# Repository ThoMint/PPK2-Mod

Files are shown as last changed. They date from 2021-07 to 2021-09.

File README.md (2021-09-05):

# PPK2-Mod

This Repository contains the documentaion for a PPK2 Modification.
The Mod extends the measurement range of the power profiler (x10 higher current resolution in the lowes range).
Further information can be found here: [Mod-Doku](https://github.com/ThoMint/PPK2-Mod/blob/master/PPK2-Mod-Bericht.pdf)

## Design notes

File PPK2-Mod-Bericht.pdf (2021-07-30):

## PPK2 Mod

Ziel des Projekts ist die Bereichserweiterung eines PPK2s, dem Power Profiling Kit von Nordic. PC Software und Hardware ist Open Source. Die Messbereichserweiterung soll die Auflösung im Nano-Ampere-Bereich erhöhen.

Das PPK2 erreicht seine hohe Dynamik über 5 Ranges die analog durchgeschalten werden.
Der Range Switch wird durch Über- oder Unterspannung am Ausgang des Instrumentation Amplifiers ausgelöst.

Da der Range Switch somit unabhängig von den jeweiligen Shunt-Widerständen schaltet ist eine Messbereichsverschiebung leicht möglich indem alle Shunt-Widerstände um eine Dekade erhöht werden.

Simulationen

…zur weiteren Evaluierung und zum Verständnis der weniger gut dokumentierten Schaltung

Simulationsprogramm: Microcap

Instrumentation Amplifier

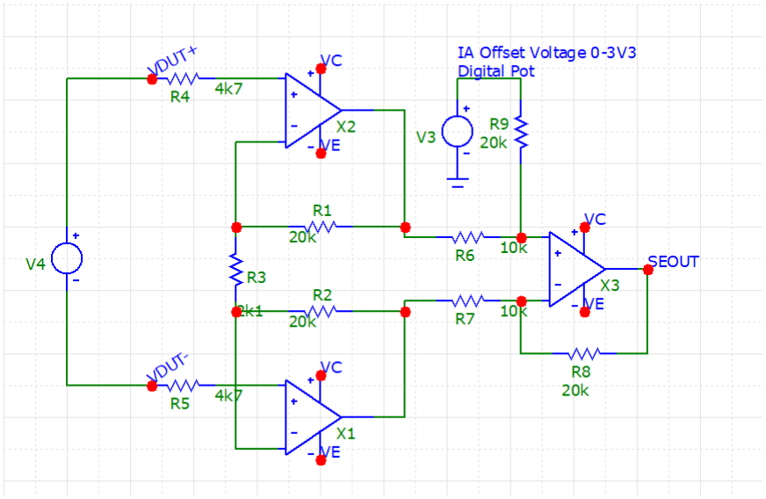
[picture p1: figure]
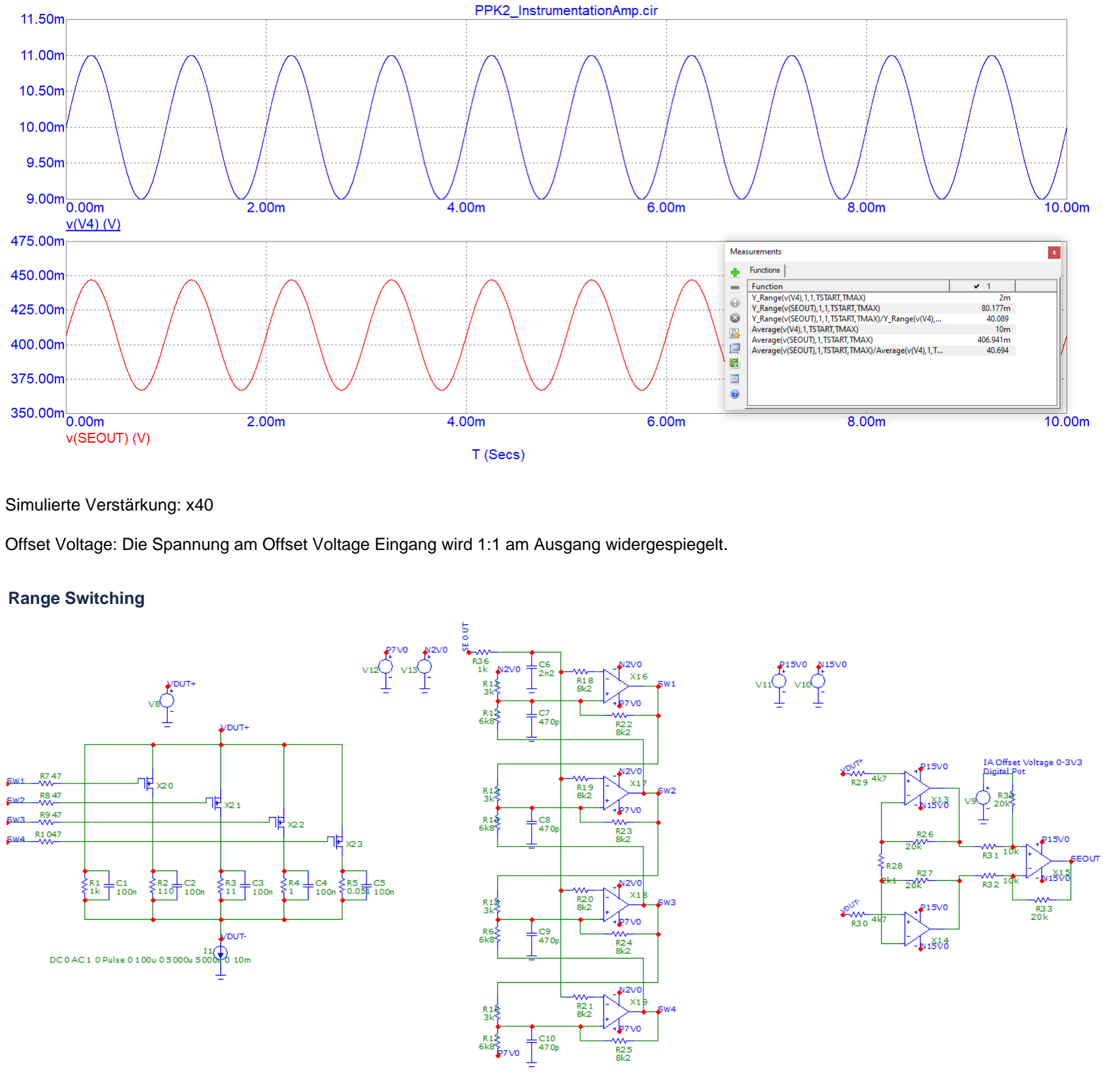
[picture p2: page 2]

Simulierte Verstärkung: x40

Offset Voltage: Die Spannung am Offset Voltage Eingang wird 1:1 am Ausgang widergespiegelt.

Range Switching

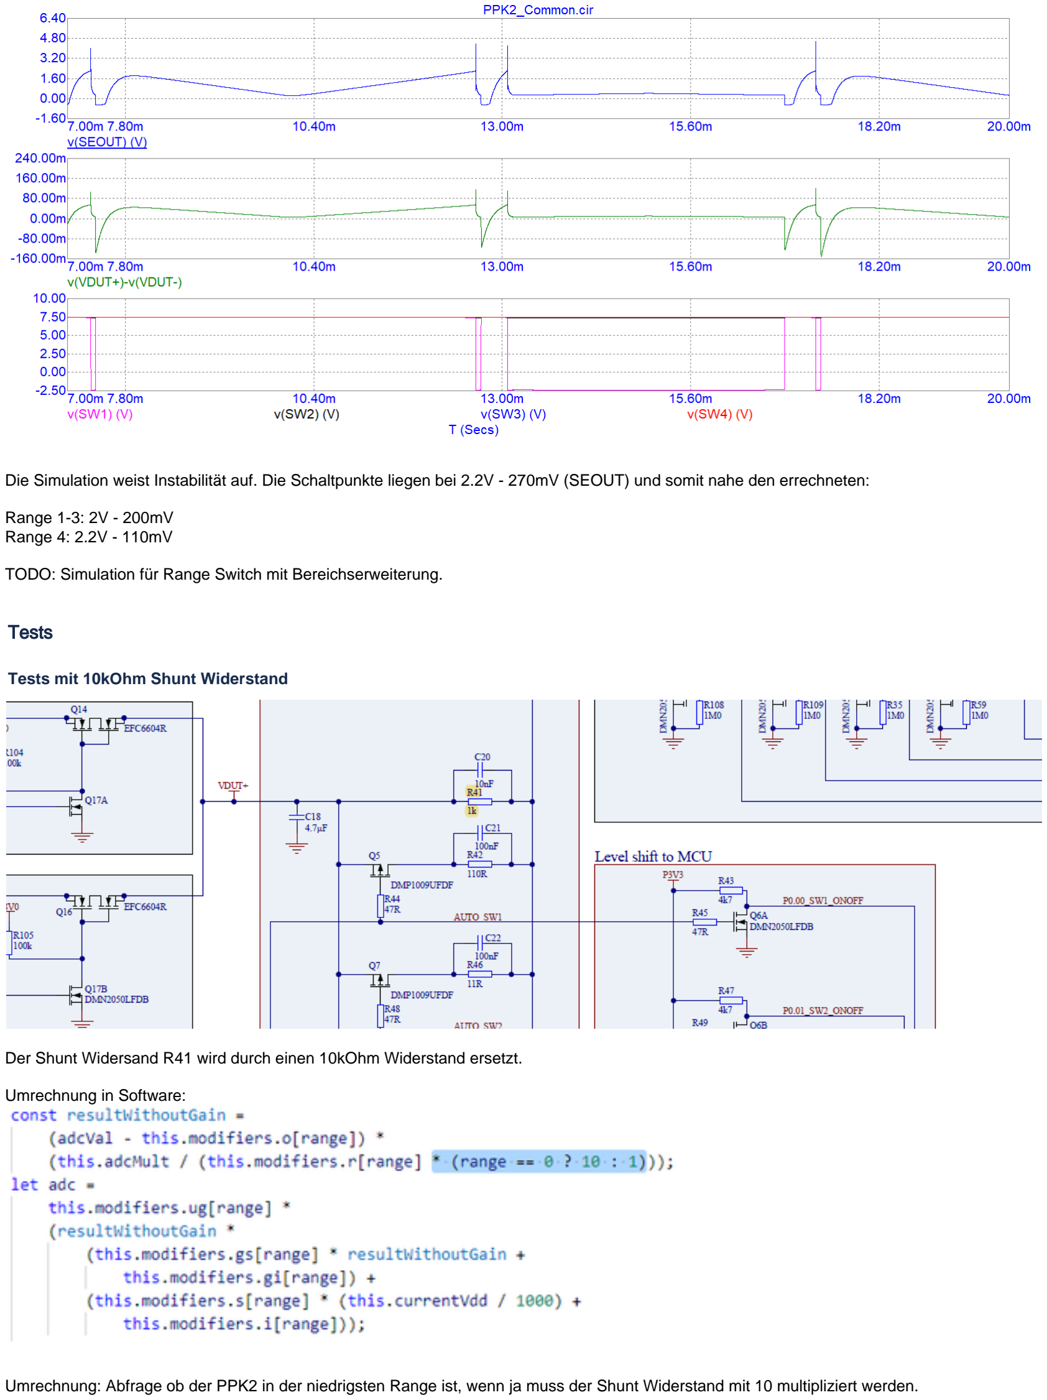
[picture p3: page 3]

Die Simulation weist Instabilität auf. Die Schaltpunkte liegen bei 2.2V - 270mV (SEOUT) und somit nahe den errechneten:

Range 1-3: 2V - 200mV
Range 4: 2.2V - 110mV

TODO: Simulation für Range Switch mit Bereichserweiterung.

Tests

Tests mit 10kOhm Shunt Widerstand

Der Shunt Widersand R41 wird durch einen 10kOhm Widerstand ersetzt.

Umrechnung in Software:

Umrechnung: Abfrage ob der PPK2 in der niedrigsten Range ist, wenn ja muss der Shunt Widerstand mit 10 multipliziert werden.

Resultat: Durch fehlende Kalibration und 1% Widerstandstoleranz ist das Ergebnis im richtigen Bereich aber nicht exakt.

Bei ungünstigen Lastströmen begibt sich der analoge Range Switch in eine Oszillation da die vorhandene Hysterese nicht mehr ausreicht um den Messbereich über 2 Dekaden hinweg stabil zu halten.

Tests mit Messbereichsversatz

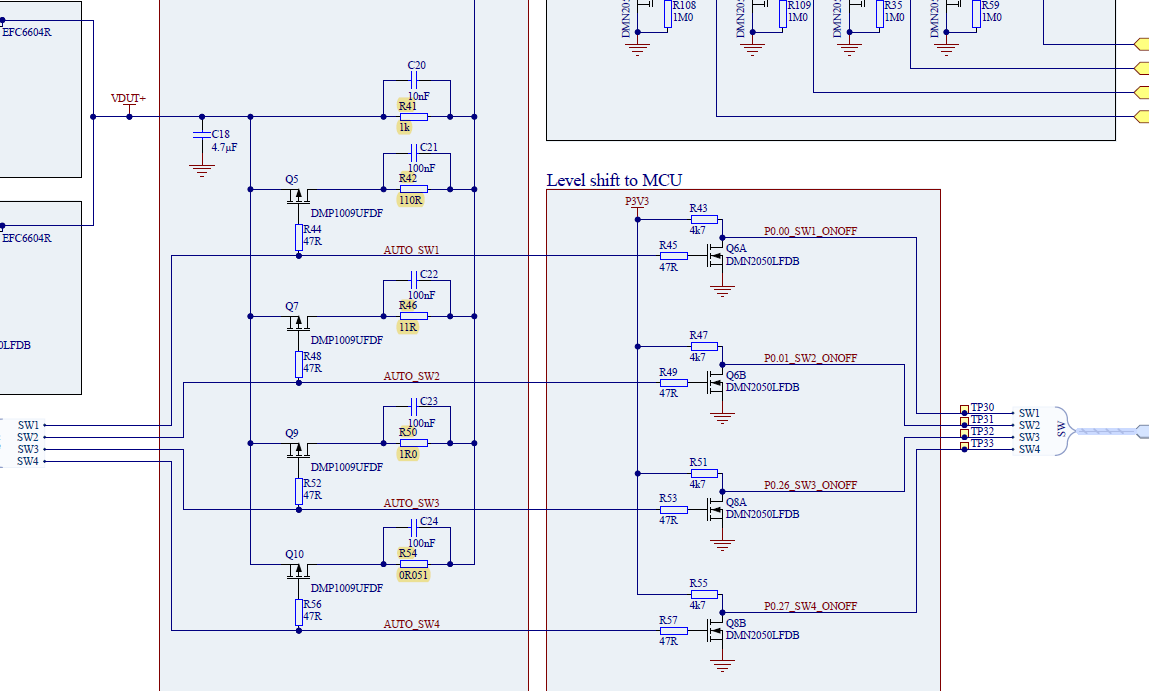
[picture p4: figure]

R41,R42,R46,R50,R54 werden jeweils um eine Dekade (Faktor x10) erhöht. Dadurch verschiebt sich der Messbereich. Das PPK2 verliert dadurch seine High Current Capabilities, gewinnt jedoch Auflösung im nA Bereich.

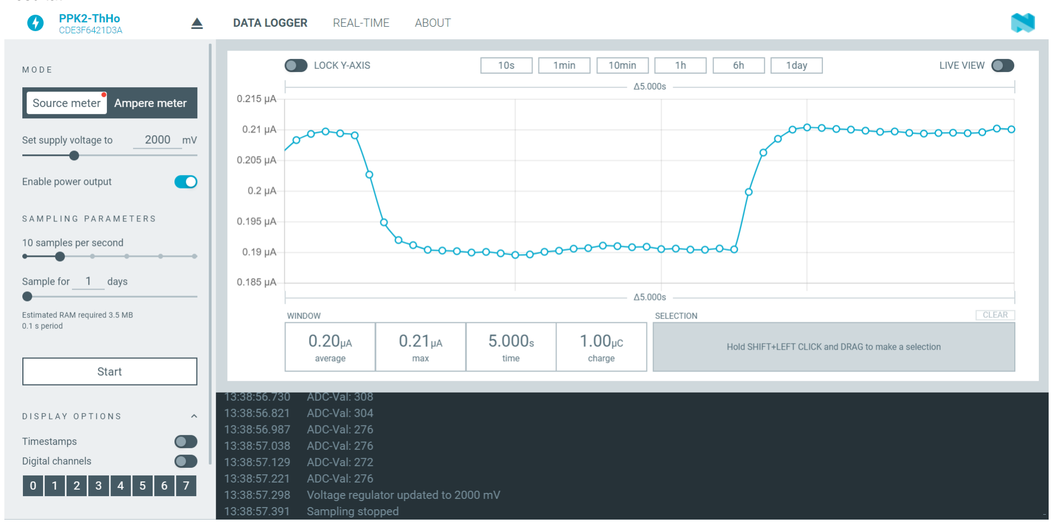
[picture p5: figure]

Resultat:

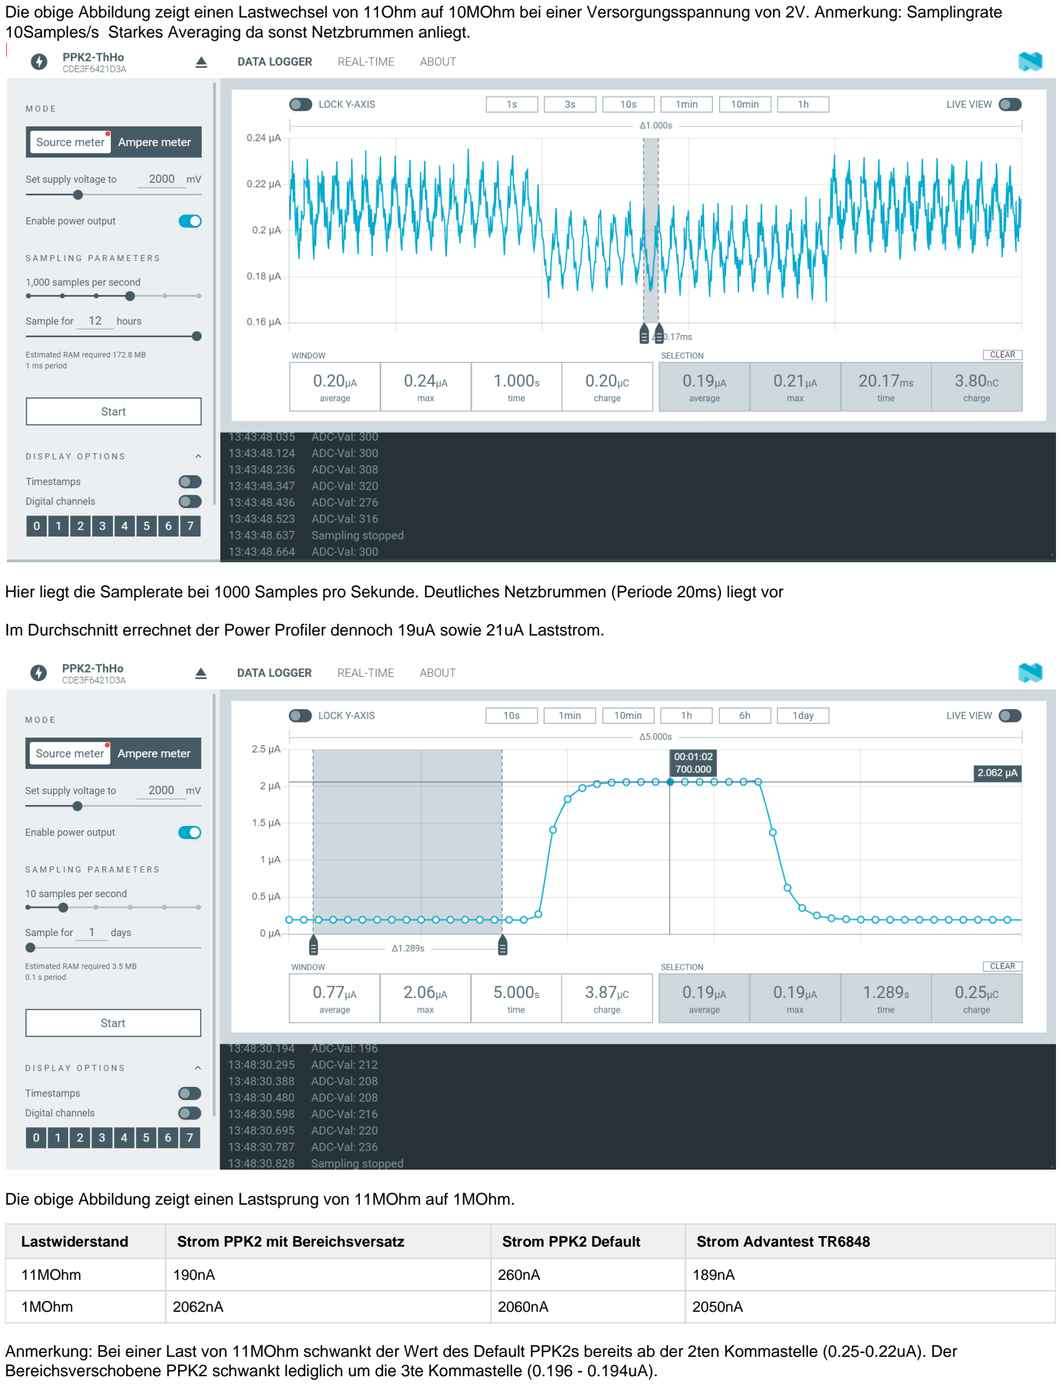
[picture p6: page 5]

Die obige Abbildung zeigt einen Lastwechsel von 11Ohm auf 10MOhm bei einer Versorgungsspannung von 2V. Anmerkung: Samplingrate 10Samples/s Starkes Averaging da sonst Netzbrummen anliegt.

Hier liegt die Samplerate bei 1000 Samples pro Sekunde. Deutliches Netzbrummen (Periode 20ms) liegt vor

Im Durchschnitt errechnet der Power Profiler dennoch 19uA sowie 21uA Laststrom.

Die obige Abbildung zeigt einen Lastsprung von 11MOhm auf 1MOhm.

Lastwiderstand | Strom PPK2 mit Bereichsversatz | Strom PPK2 Default | Strom Advantest TR6848
11MOhm | 190nA | 260nA | 189nA
1MOhm | 2062nA | 2060nA | 2050nA

Anmerkung: Bei einer Last von 11MOhm schwankt der Wert des Default PPK2s bereits ab der 2ten Kommastelle (0.25-0.22uA). Der Bereichsverschobene PPK2 schwankt lediglich um die 3te Kommastelle (0.196 - 0.194uA).

Da durch die vorherigen Tests eine Bereichserweiterung sinnvoll erscheint wird diese in den nächsten Schritten durchgeführt und getestet.

Bereichserweiterung 1A-10nA

Hardwareänderungen

Da die Messbereiche vorwiegend von den Shunt-Widerständen abhängen können diese einfach ausgetauscht werden indem man alle Widerstandswerte x10 multipliziert. Dadurch wird der Messbereich verschoben. Da das gewünschte Ergebnis jedoch eine Messbereichserweiterung ist muss hier der kleinste Shunt Widerstand gleich bleiben. Der kleinste Messbereich wird um einen Faktor 10 verkleinert.

Die Bereiche dazwischen müssen nun anders aufgeteilt werden. Eine logarithmische Verteilung ist notwendig:

Dimensionierung der Bereich mit Python per Geomspace (NumPy):
https://trinket.io/python3/8aac81c5b8

Daraus ergeben sich folgende Logarithmisch verteilten Widerstandswerte: 50mOhm, 1Ohm, 22Ohm, 470Ohm, 10kOhm

Herstellernummern:

ERJL03KF50MV

ERA3APB471V

RT0603DRD0710KL

CRCW06031R00FKEAHP

ERJ3RED22R0V

Widerstandsgehäuse: 0603, Original-Footprint: 0402

Größere Widerstandsgehäuse haben von Natur aus weniger Eigenerwärmung und sind somit besser als Shunt-Widerstände geeignet. Problematik: Mögliche kalte Lötstellen da die Pads nicht gut erreichbar sind.

Problematik: Durch die höheren Messbereiche ergeben sich auch andere Spannungspegel am Ausgang des Instrumentation Amplifiers. Der Automatic Range Switch schaltet dadurch nicht mehr richtig und begibt sich bei einigen Stromwerten zwischen den Bereichen in eine Oszillation. (Starkes Negatives Feedback wie bereits in der Simulation zu sehen)

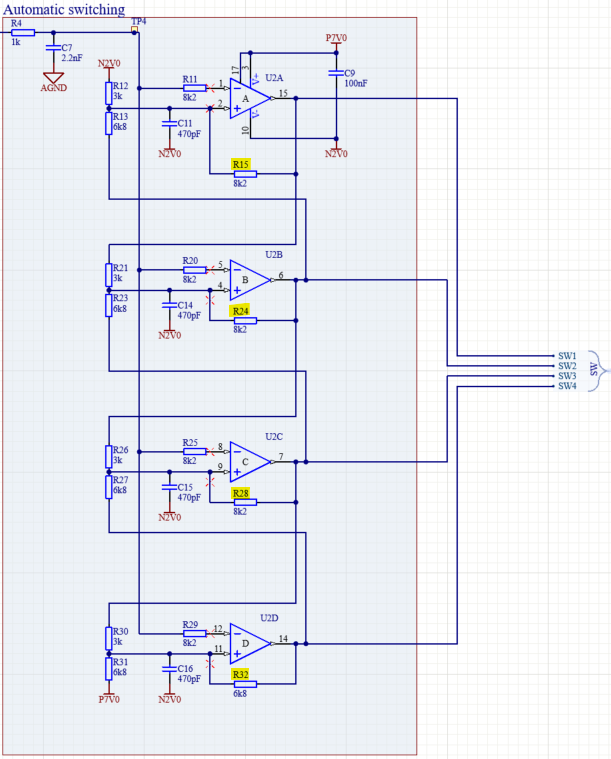
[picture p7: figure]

Die Widerstände R15, R24, R28, R32 bestimmen die Hysterese und somit auch die Schaltschwellen. Kleiner Widerstandswerte an diesen Stellen ergeben eine höhere Hysterese und somit einen weiteren Bereich bis zur nächsten Schaltschwelle (Hysterese durch verschieben der Referenzspannung an Vin+).

Dimensionierung: Trial and Error. Durch langsames herantasten (inkrementelles verkleinern der Widerstandswerte) wurden die Widerstände R15, R24, R28, R32 auf 6k2 festgelegt.

Eine weitere Verkleinerung dieser Widerstände bewirkt dass Ranges nicht mehr bzw. zu Spät schalten und somit der ADC oben oder unten an seine Eingangsspannungsgrenzen kommt.

Durch die neuen Range-Hysterese Widerstände ergeben sich ADC-Counts von 150Cnts bis 6000Cnts (ADC Counts nach Gain-Correction, Spannungswerte nahe Aussteuergrenzen, 14Bit ADC)

Softwareänderungen

Die meiste Funktionalität des Geräts wird durch die Software erreicht. Die Firmware liefert lediglich raw ADC Counts sowie die derzeitige Range und beim Verbinden des Geräts die ab-Werk Kalibrationsdaten.

Da die Kalibrationsdaten (auf einem I2C EEPROM auf dem Gerät gespeichert) nicht mit den neuen Widerständen und Bereichen kompatibel sind, muss die Kalibration neu durchgeführt werden.

Das originale Kalibrationsmodell ist unübersichtlich und nicht definierbar. Es bleibt unklar welche Korrekturen hier vorgenommen werden und wie die Faktoren berechnet werden.

Abhilfe: Neues, transparentes Kalibrationsmodell:
9 Punkt (pro Range) Kalibration über Eingangsspannung und Strom.

Kalibrationsdaten der Range 0:

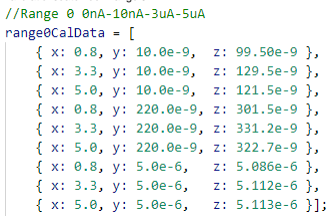
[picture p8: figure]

x: DUT Spannung in V
y: Referenz Strom von bekannter und geeichter Stromquelle
z: Ausgangs Strom des PPK2s ohne Kalibration (Offset = 0 wenn y=z)

Diese Kalibrationsdaten werden bilinear Interpoliert um eine bessere Abdeckung der Range zu erreichen.

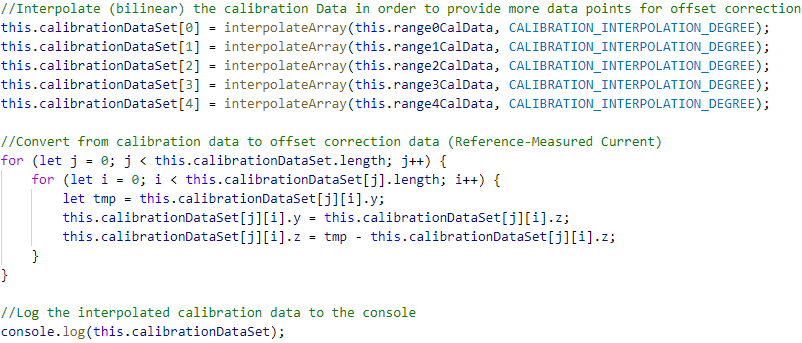
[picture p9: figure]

Interpolation:

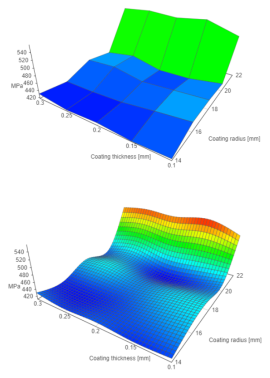
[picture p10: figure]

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
Achtung: Abbildungen nur Symbolbilder, repräsentieren nicht die tatsächlichen Kalibrationsdaten

Durch diese Art der Kalibration ergibt sich ein Abbild des Gesamten Messbereichs.

Umrechnen von ADC Counts zu Strom:

Der Offset wird als der nächste Wert in der Kennlinie (kleinster Abstand über Pythagoras) angenommen.

Weitere Änderungen der Software:

-Debug Statements im Logger der Software (Betriebsspannung, Range, Widerstand, Offset, etc.) -Erhöhung der Kommastellen der Stats Anzeigen (Average, Maximum und Charge)

Kalibrationsvorgang

Kalibrationsdatentabell in “src\device\serialDevice.js” für die entsprechende Range editieren: Gewünschte DUT Spannungen eintragen
Gewünschte Referenz-Ströme eintragen
Ausgangsströme gleich den Referenz-Strömen setzten (y=z->Offset = y-z = 0)
Die Sotware neu Kompillieren. Kompletter Guide zum aufsetzen und kompillieren eines Node.js Projekts unter: https://nordicsemiconductor.github.io/pc-nrfconnect-docs/app_development (https://nordicsemiconductor.github.io/pc-nrfconnect-docs/app_development)
Messtabelle durchgehen
DUT Spannung einstellen
Strom bei Stromquelle einstellen (als Stromsenke!!!)
Warten bis sich das Average-Reading eingestellt hat
Average Current aus der Software nRF Connect in die Tabelle übertragen Code abspeichern und nRF Connect Power Profiler neu kompillieren

Die Referenz - Daten wurden:

-für die DUT Spannung Linear aufgeteilt (0.8V = Min, 3.3V, 5V = Max)

-für den Eingangsstrom geometrisch gemittelt (Range-Min, geom. Mittel der Range, Range-Max)

Der Interpolationsgrad wird über die Konstante CALIBRATION_INTERPOLATION_DEGREE eingestellt.

Weiters müssen die richtigen Widerstandwerte eingetragen werden (“src\device\serialDevice.js:150”) Hier reichen die idealen Werte, der Rest wird durch die Kalibration korrigiert.

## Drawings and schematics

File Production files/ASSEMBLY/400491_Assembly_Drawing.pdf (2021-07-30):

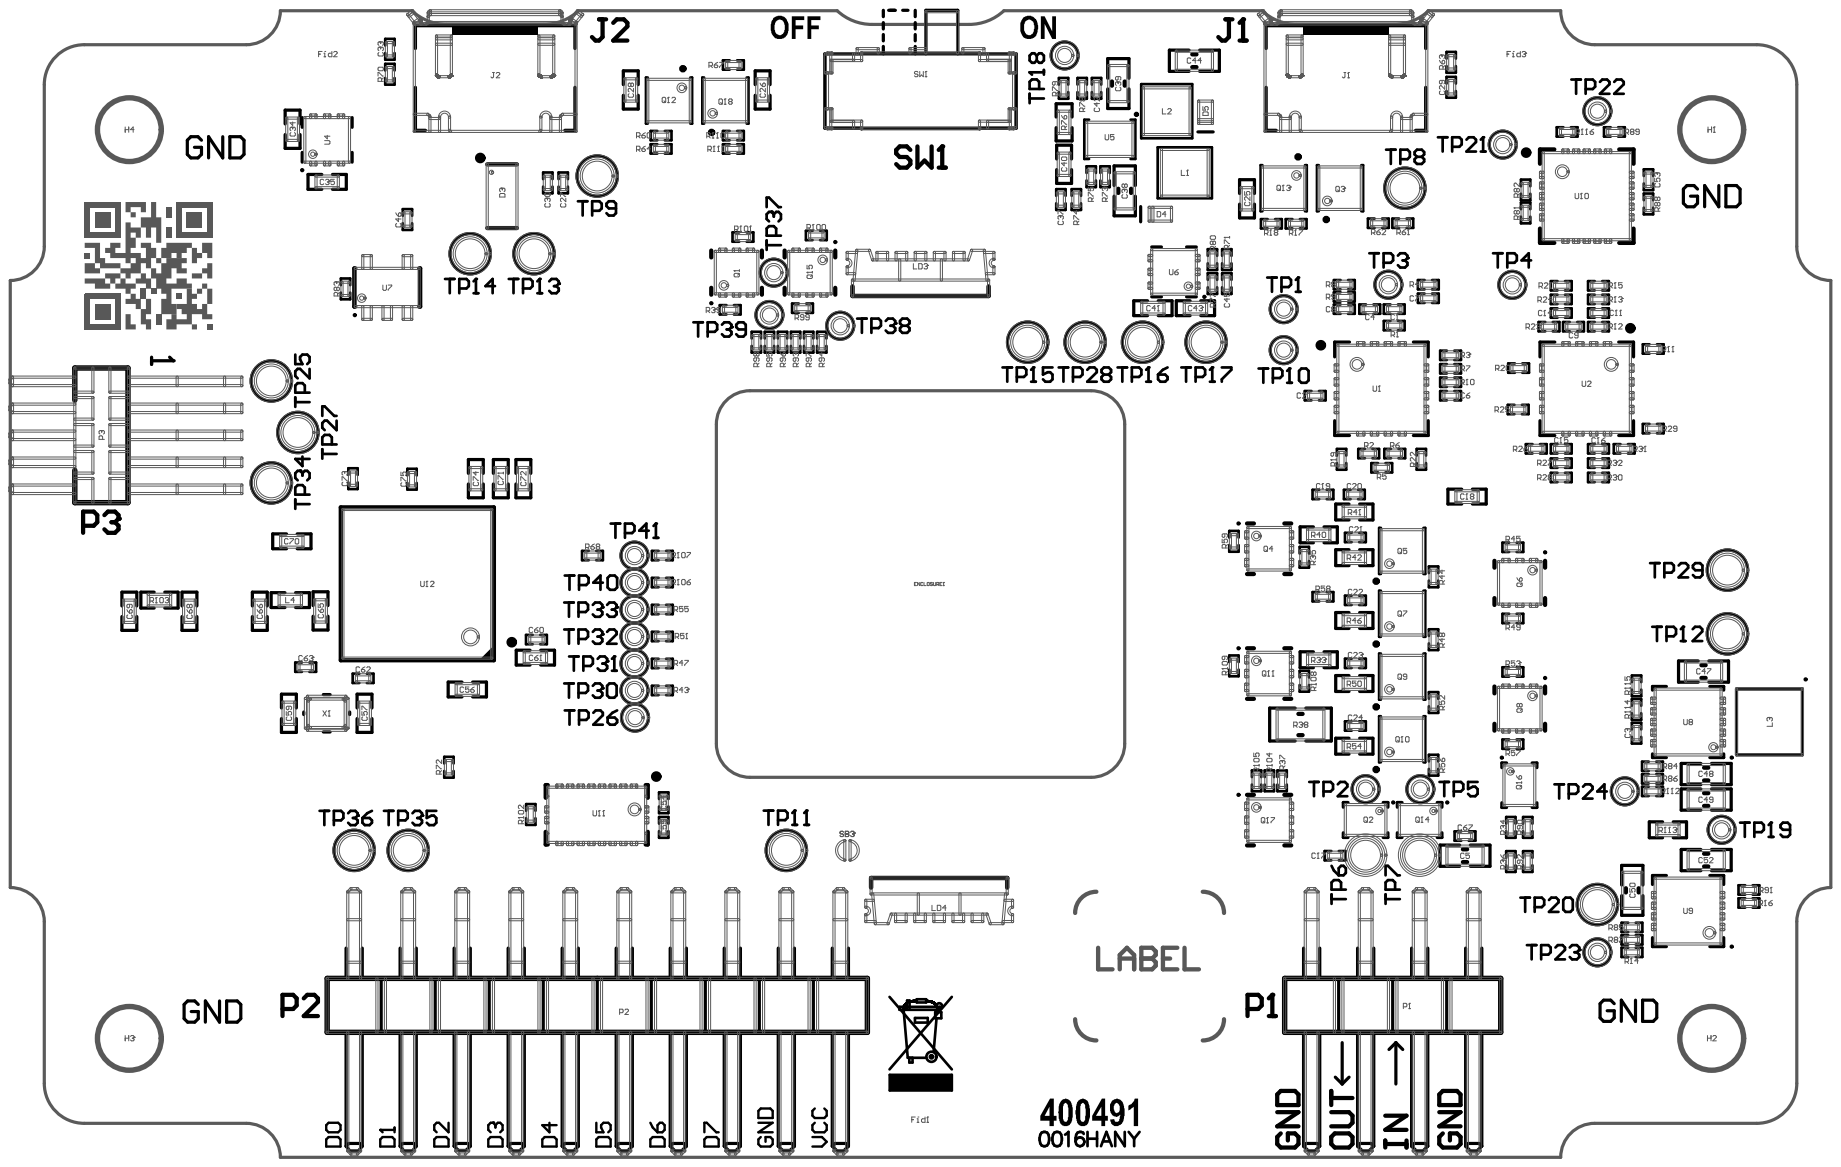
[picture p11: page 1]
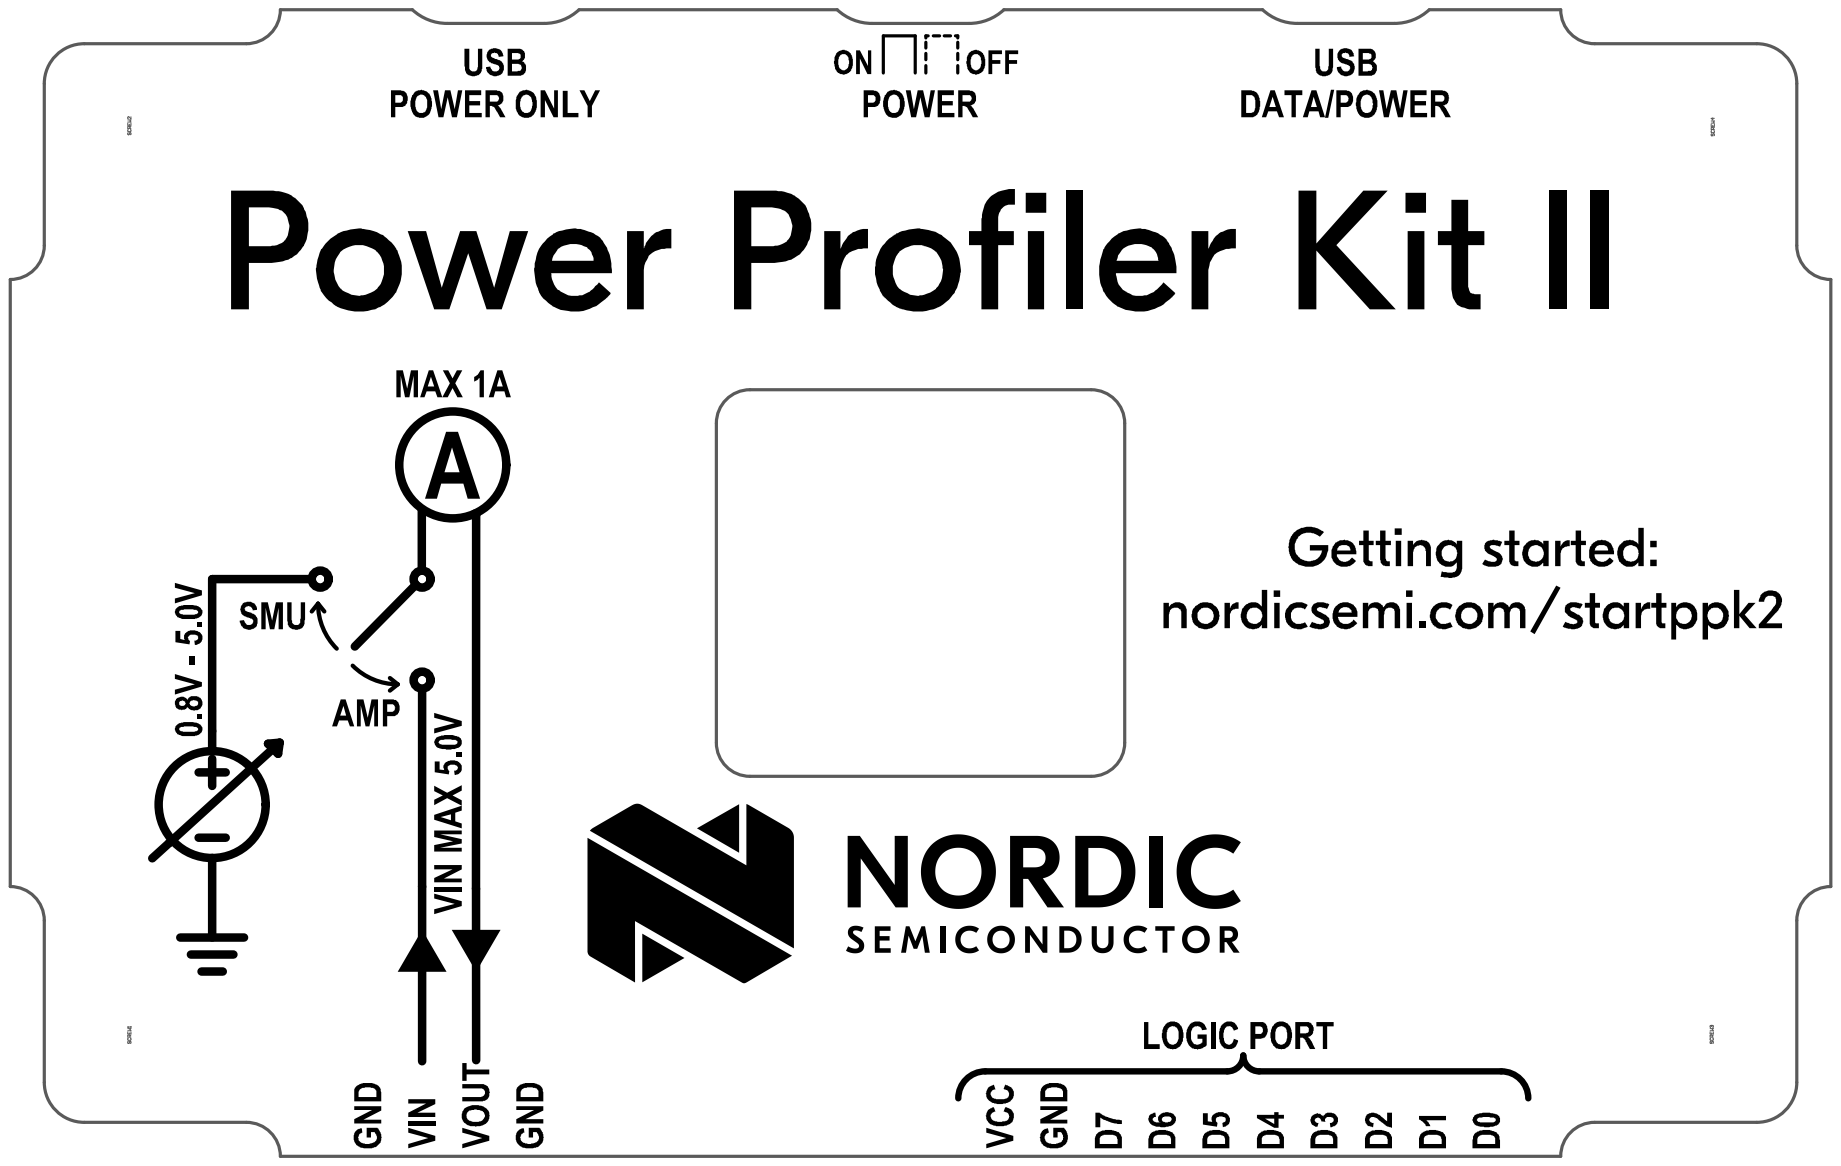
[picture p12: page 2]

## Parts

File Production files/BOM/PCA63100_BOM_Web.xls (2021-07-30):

Bill of material
Board: | pca63100
Version: | 1.0.1
Designator | Value | Description | Fitted | Footprint Doc | Manufacturer | Manufacturer Part Number
C2, C3, C9, C21, C22, C23, C24, C27, C46, C53, C54, C55, C60, C62, C67, C73, C75 | 100nF | Capacitor, X5R, ±10% | Fitted | 0201
C5, C38, C39, C44, C47, C48, C49, C50, C52 | 10µF | CAP CER 10UF 10V X7T 0603 | Fitted | 0603 | Murata | GRM188D71A106MA73
C7, C37, C42 | 2.2nF | Capacitor, X7R, ±10%, 10V | Fitted | 0201
C8 | 1.0nF | Capacitor, X7R, ±10% | Fitted | 0201
C11, C14, C15, C16 | 470pF | Chip Cap 0201 | Fitted | 0201
C17, C19, C20, C30 | 10nF | Capacitor, X7R, ±10% | Fitted | 0201
C18, C25, C26, C28, C34, C35, C41, C43, C71, C72, C74 | 4.7µF | Capacitor, X5R, ±20% | Fitted | 0402
C40, C56, C61 | 1.0µF | Capacitor, X5R, ±5%, 6.3V | Fitted | 0402
C45 | 1.0µF | Capacitor, X5R, ±10% | Fitted | 0201
C57, C59 | 12pF | Capacitor, NP0, ±2% | Fitted | 0402
C63 | 100pF | Capacitor, NP0, ±2%, 25V | Fitted | 0201 | Murata | GRM0335C1E101GA01
C70 | 820pF | Capacitor, NP0, ±5% | Fitted | 0402
D3 | PRTR5V0U2X | Ultra low capacitance double rail-to-rail ESD protection diode | Fitted | SOT-143B | NXP | PRTR5V0U2X
D4, D5 | PMEG2005AELD | DIODE SCHOTTKY 20V 0.5A DFN1006D-2/SOD882D | Fitted | DFN1006D-2 | NXP | PMEG2005AELD, 315
ENCLOSURE1 | Plastic Enclosure | PPK2 Moulded plastic casing | Fitted | Plastic casing | Proto Labs, Inc. | PPK plexi rev 1.2
J1, J2 | MicroUSB-B | MicroUSB-B-SMT | Fitted | USB-Micro-B-RA-SMD-PiP | Allen Creations Corp. | AJU55-BS2111-L
L1, L2 | 4.7µH | Shielded Power Inductor EPL2014 Low DCR Ind 4.7 uH 20 % 650mA | Fitted | IND_EPL2014 | Coilcraft | EPL2014-472MLC
L3 | 1.5µH | Ferrite Inductor, Shielded, 1,8A, 48mOhm | Fitted | 1212 | Taiyo Yuden | NR3015T1R5N
LD3, LD4 | LED RGB | High brightness, side view RGB LED | Fitted | 6922 | ROHM | MSL0104RGBU1
P1 | Pin List 1x4, Angled | Pin List 1x4, 2.54mm (100mil), Right Angled, SMD | Fitted | LIST_ANG_1x4-SMD-2.54MM
P2 | Pin List 1x10, Angled | Pin List 1x10, 2.54mm (100mil), Right Angled, SMD | Fitted | LIST_ANG_1x10-SMD-2.54MM
Q1, Q4, Q6, Q8, Q11, Q15, Q17 | DMN2050LFDB | Dual N Ch MOFET, 3.3A, 45mOhm @ 5A, 4.5V, 730mW | Fitted | DFN-6 | Diodes Incorporated | DMN2050LFDB-7
Q2, Q14, Q16 | EFC6604R | Dual MOSFET, Dual N Channel, 13 A, 12 V, 0.009 ohm, 4.5 V, 2.5 V | Fitted | WLCSP-6 | ON Semiconductor | EFC6604R-TR
Q3, Q5, Q7, Q9, Q10, Q12, Q13, Q18 | DMP1009UFDF | P Ch MOFET, 11A, 30mOhm max, 2W | Fitted | UDFN-6 | Diodes Incorporated | DMP1009UFDF
R1, R2, R6, R10, R75 | 20k | Resistor, ±0.1%, 0.031W | Fitted | 0201
R3, R7, R8, R9, R58, R60, R62, R72 | 10k | Resistor, ±0.1%, 0.031W | Fitted | 0201
R4, R71 | 1k | Resistor, ±1%, 0.05W | Fitted | 0201
R5 | 2.1k | RES SMD 2.1K OHM 1% 1/20W 0201 | Fitted | 0201 | Panasonic | ERJ-1GEF2101C
R11, R15, R20, R24, R25, R28, R29 | 8k2 | Resistor, ±1%, 0.05W | Fitted | 0201
R12, R21, R26, R30 | 3k | Resistor, ±1%, 0.05W | Fitted | 0201
R13, R23, R27, R31, R32 | 6k8 | Resistor, ±1%, 0.05W | Fitted | 0201
R14 | 220k | Resistor, ±1%, 0.05W | Fitted | 0201
R16, R34, R90, R110 | 120k | Resistor, ±1%, 0.05W | Fitted | 0201
R17, R74, R78 | 56k | Resistor, ±1%, 0.05W | Fitted | 0201
R18, R37, R61, R67, R68, R83, R88, R102, R104, R105 | 100k | Resistor, ±1%, 0.05W | Fitted | 0201
R19, R22, R43, R47, R51, R55, R81, R82 | 4k7 | Resistor, ±1%, 0.05W | Fitted | 0201
R33, R41 | 1k | Resistor, ±0.1%, 0.063W | Fitted | 0402
R35, R39, R59, R64, R99, R100, R101, R106, R107, R108, R109 | 1M0 | Resistor, ±1%, 0.05W | Fitted | 0201
R36, R91, R92, R111 | 30k | Resistor, ±1%, 0.05W | Fitted | 0201
R38 | 100R | Resistor, ±1%, 0.125W | Fitted | 0805
R40 | 100k | Resistor, ±0.1%, 0.063W | Fitted | 0402
R42 | 110R | Resistor, ±1%, 0.063W | Fitted | 0402
R44, R45, R48, R49, R52, R53, R56, R57, R94, R95, R97, R98 | 47R | Resistor, ±1%, 0.05W | Fitted | 0201
R46 | 11R | Resistor, ±1%, 0.063W | Fitted | 0402
R50 | 1R0 | Resistor, ±1%, 0.063W | Fitted | 0402
R54 | 0R051 | RES SMD 0.051 OHM 1% 1/4W 0402 | Fitted | 0402 | Panasonic | ERJ-2BWFR051X
R73 | 180k | Resistor, ±1%, 0.05W | Fitted | 0201
R76 | 160k | Resistor, ±0.1%, 0.063W | Fitted | 0402
R77, R84, R85, R112 | 330k | Resistor, ±1%, 0.05W | Fitted | 0201
R79, R116 | 560k | Resistor, ±1%, 0.05W | Fitted | 0201
R80 | 68k | Resistor, ±1%, 0.05W | Fitted | 0201
R86 | 33k | Resistor, ±1%, 0.05W | Fitted | 0201
R87 | 82k | Resistor, ±1%, 0.05W | Fitted | 0201
R89, R114 | 0R | Resistor, ±5%, 0.05W | Fitted | 0201
R93, R96 | 180R | Resistor, ±1%, 0.05W | Fitted | 0201
R113 | 10k | THERMISTOR 10K OHM NTC 0402 SMD | Fitted | 0402 | Murata | NCP15XH103F03RC
SCREW1, SCREW2, SCREW3, SCREW4 | Screw | Pan head, torx, 2.5x5mm screw | Fitted | T8 screw | Bossard | 3205129
SW1 | Switch | SMD slide Switch (ON-ON) | Fitted | Switch-Slide-RA-J-Lead-DPDT-8.5x3.5mm | Copal Electronics Inc | CL-SB-22A-11T
U1, U2 | ADA4622 | J-FET Amplifier 4 Circuit Rail-to-Rail 16-LFCSP (4x4) | Fitted | QFN-16 | Analog Devices | ADA4622-4ACPZ-RL
U4 | ADP151 | Ultralow Noise, 200 mA,CMOS Linear Regulator | Fitted | UDFN-6 | Analog Devices | ADP151ACPZ-3.3-R7
U5 | ADP5072 | Boost Switching Regulator IC Positive and Negative (Dual Rail) Adjustable 0.8V 2 Output 600mA, 1A 20-UFBGA, | Fitted | BGA-20 | Analog Devices | ADP5072ACBZ-R7
U6 | ADP7118 | 20 V, 200 mA, Low Noise,CMOS LDO Linear Regulator | Fitted | UDFN-6 | Analog Devices | ADP7118ACPZN-R7
U7 | 24CW160 | 16 Kbit I2C Serial EEPROM with Software Write Protection, 1.6-5.5 V Supply | Fitted | TSOT23-5 | Microchip | 24CW160T-I/OT
U8 | ADP2504 | Buck-Boost Switching Regulator IC Positive Adjustable 2.8V 1 Output 1A | Fitted | LFCSP-10 | Analog Devices | ADP2504ACPZ-R7
U9 | ADP1708 | LDO, Adjustable, 1 Output 1A, 8-LFCSP-WD (3x3) | Fitted | UDFN-8 | Analog Devices | ADP1708ACPZ-R7
U10 | MCP4451_100k | Quad Digital Potentiometer, 100k, 257 taps, I2C interface, Volatile Memory, 1.8-5.5V | Fitted | QFN-20 | Microchip Technology | MCP4451-104E/ML
U11 | FXMA108 | 8-bit bidirectional voltage-level translator with auto-direction sensing | Fitted | DQFN-20 | Fairchild Semiconductor | FXMA108BQX
U12 | nRF52840-QIAA | Multi-protocol Bluetooth Low Energy, IEEE 802.15.4, ANT and 2.4GHz proprietary system-on-chip | Fitted | AQFN-73 | Nordic Semiconductor | nRF52840-QIAAD0
X1 | 32MHz | XTAL SMD 2016, 32MHz, Cl=8pF, Total Tol: ±40ppm | Fitted | XTAL_2016
C1, C6 | 2.2pF | Chip Cap 0201 | Not Fitted | 0201
C4 | 1.0nF | Capacitor, X7R, ±10% | Not Fitted | 0201
C29, C33 | 4.7nF | Chip Cap 0201 | Not Fitted | 0201
C65 | 0.8pF | Capacitor, NP0, ±5% | Not Fitted | 0402 | Murata | GRM1555C1HR80WA01D
C66 | 0.5pF | Capacitor, NP0, ±0.05pF | Not Fitted | 0402 | Murata | GJM1555C1HR50WB01
C68, C69 | N.C. | Not mounted | Not Fitted | 0402
L4 | 4.7nH | Inductor, 160mA, ±0.1nH | Not Fitted | 0402 | Murata | LQP15MN4N7B02D
P3 | Pin Header 2x5 | Pin Header 2x5, 1.27mm (50mil) | Not Fitted | HDR_2x5-SMD-1.27mm-ANG | W-CON | 1325B-1205S0Z080CR02
R63, R70 | 1M0 | Resistor, ±1%, 0.05W | Not Fitted | 0201
R103 | 0R | Resistor, ±5%, 0.063W | Not Fitted | 0402
R115 | 0R | Resistor, ±5%, 0.05W | Not Fitted | 0201
